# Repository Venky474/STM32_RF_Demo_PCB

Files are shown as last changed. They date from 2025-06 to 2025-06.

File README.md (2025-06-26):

# STM32_RF_Demo_PCB

This is a custom STM32 RF PCB designed using KiCad.

## Contents
- 🧩 KiCad Project Files (`.kicad_pro`, `.kicad_pcb`, `.kicad_sch`)
- 📦 Gerber Files (in `.rar`)
- 📄 BOM: `BOM_Output.csv`
- 🤖 Pick and Place: `STM32_RF.cpl`

## Preview

Preview of the STM32_RF PCB layout (generated using KiCad 3D viewer).
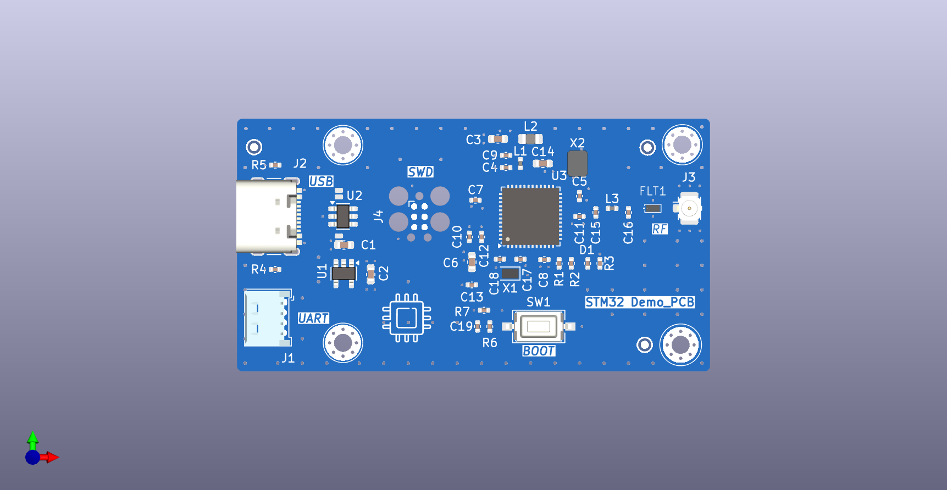
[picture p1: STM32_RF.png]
3D PCB View


## License
[MIT](LICENSE) or specify your own

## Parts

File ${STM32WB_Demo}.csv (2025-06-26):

Reference | Value | Footprint | Datasheet | Qty | DNP | Exclude from BOM | Exclude from Board
C1,C2,C3,C6,C14 | 4.7uF | Capacitor_SMD:C_0603_1608Metric | ~ | 5
C4,C5,C7,C8,C9,C10,C11,C12,C13,C19 | 100nF | Capacitor_SMD:C_0402_1005Metric | ~ | 10
C15 | 0.8pF | Capacitor_SMD:C_0402_1005Metric | ~ | 1
C16 | 0.3pF | Capacitor_SMD:C_0402_1005Metric | ~ | 1
C17,C18 | 10p | Capacitor_SMD:C_0402_1005Metric | ~ | 2
D1 | LED | Capacitor_SMD:C_0402_1005Metric | ~ | 1
FID1,FID2,FID3 | Fiducial | Fiducial:Fiducial_1mm_Mask2mm | ~ | 3 |  | Excluded from BOM
FLT1 | DLF162500LT-5028A1 | STM32_RF:Untitled | https://product.tdk.com/en/system/files | 1
H1,H2,H3,H4 | MountingHole_Pad | MountingHole:MountingHole_2.2mm_M2_Pad_Via | ~ | 4 |  | Excluded from BOM
J1 | Conn_01x04 | Connector_Molex:Molex_PicoBlade_53048-0410_1x04_P1.25mm_Horizontal | ~ | 1
J2 | USB_C_Receptacle_USB2.0_16P | Connector_USB:USB_C_Receptacle_GCT_USB4105-xx-A_16P_TopMnt_Horizontal | https://www.usb.org/sites/default/files/documents/usb_type-c.zip | 1
J3 | Conn_Coaxial | Connector_Coaxial:U.FL_Hirose_U.FL-R-SMT-1_Vertical | ~ | 1
J4 | TC2030 | Connector:Tag-Connect_TC2030-IDC-FP_2x03_P1.27mm_Vertical | https://www.tag-connect.com/wp-content/uploads/bsk-pdf-manager/TC2030-CTX_1.pdf | 1 |  | Excluded from BOM
L1 | 10nH | Inductor_SMD:L_0402_1005Metric | ~ | 1
L2 | 10uH | Inductor_SMD:L_0805_2012Metric | ~ | 1
L3 | 2.7nH | Inductor_SMD:L_0402_1005Metric | ~ | 1
R1,R2,R6 | 100R | Capacitor_SMD:C_0402_1005Metric | ~ | 3
R3 | 220R | Capacitor_SMD:C_0402_1005Metric | ~ | 1
R4,R5 | 5K1 | Capacitor_SMD:C_0402_1005Metric | ~ | 2
R7 | 5k1 | Capacitor_SMD:C_0402_1005Metric | ~ | 1
SW1 | SW_Push | Button_Switch_SMD:SW_Tactile_SPST_NO_Straight_CK_PTS636Sx25SMTRLFS | ~ | 1
U1 | MIC5365-3.3YD5 | Package_TO_SOT_SMD:SOT-23-5 | http://ww1.microchip.com/downloads/en/DeviceDoc/mic5365.pdf | 1
U2 | USBLC6-2SC6 | Package_TO_SOT_SMD:SOT-23-6 | https://www.st.com/resource/en/datasheet/usblc6-2.pdf | 1
U3 | STM32WB55CEU6 | Package_DFN_QFN:QFN-48-1EP_7x7mm_P0.5mm_EP5.6x5.6mm | https://www.st.com/resource/en/datasheet/stm32wb55ce.pdf | 1
X1 | 32KHz768 | Crystal:Crystal_SMD_2012-2Pin_2.0x1.2mm | ~ | 1
X2 | 32MHz | Crystal:Crystal_SMD_2016-4Pin_2.0x1.6mm | ~ | 1

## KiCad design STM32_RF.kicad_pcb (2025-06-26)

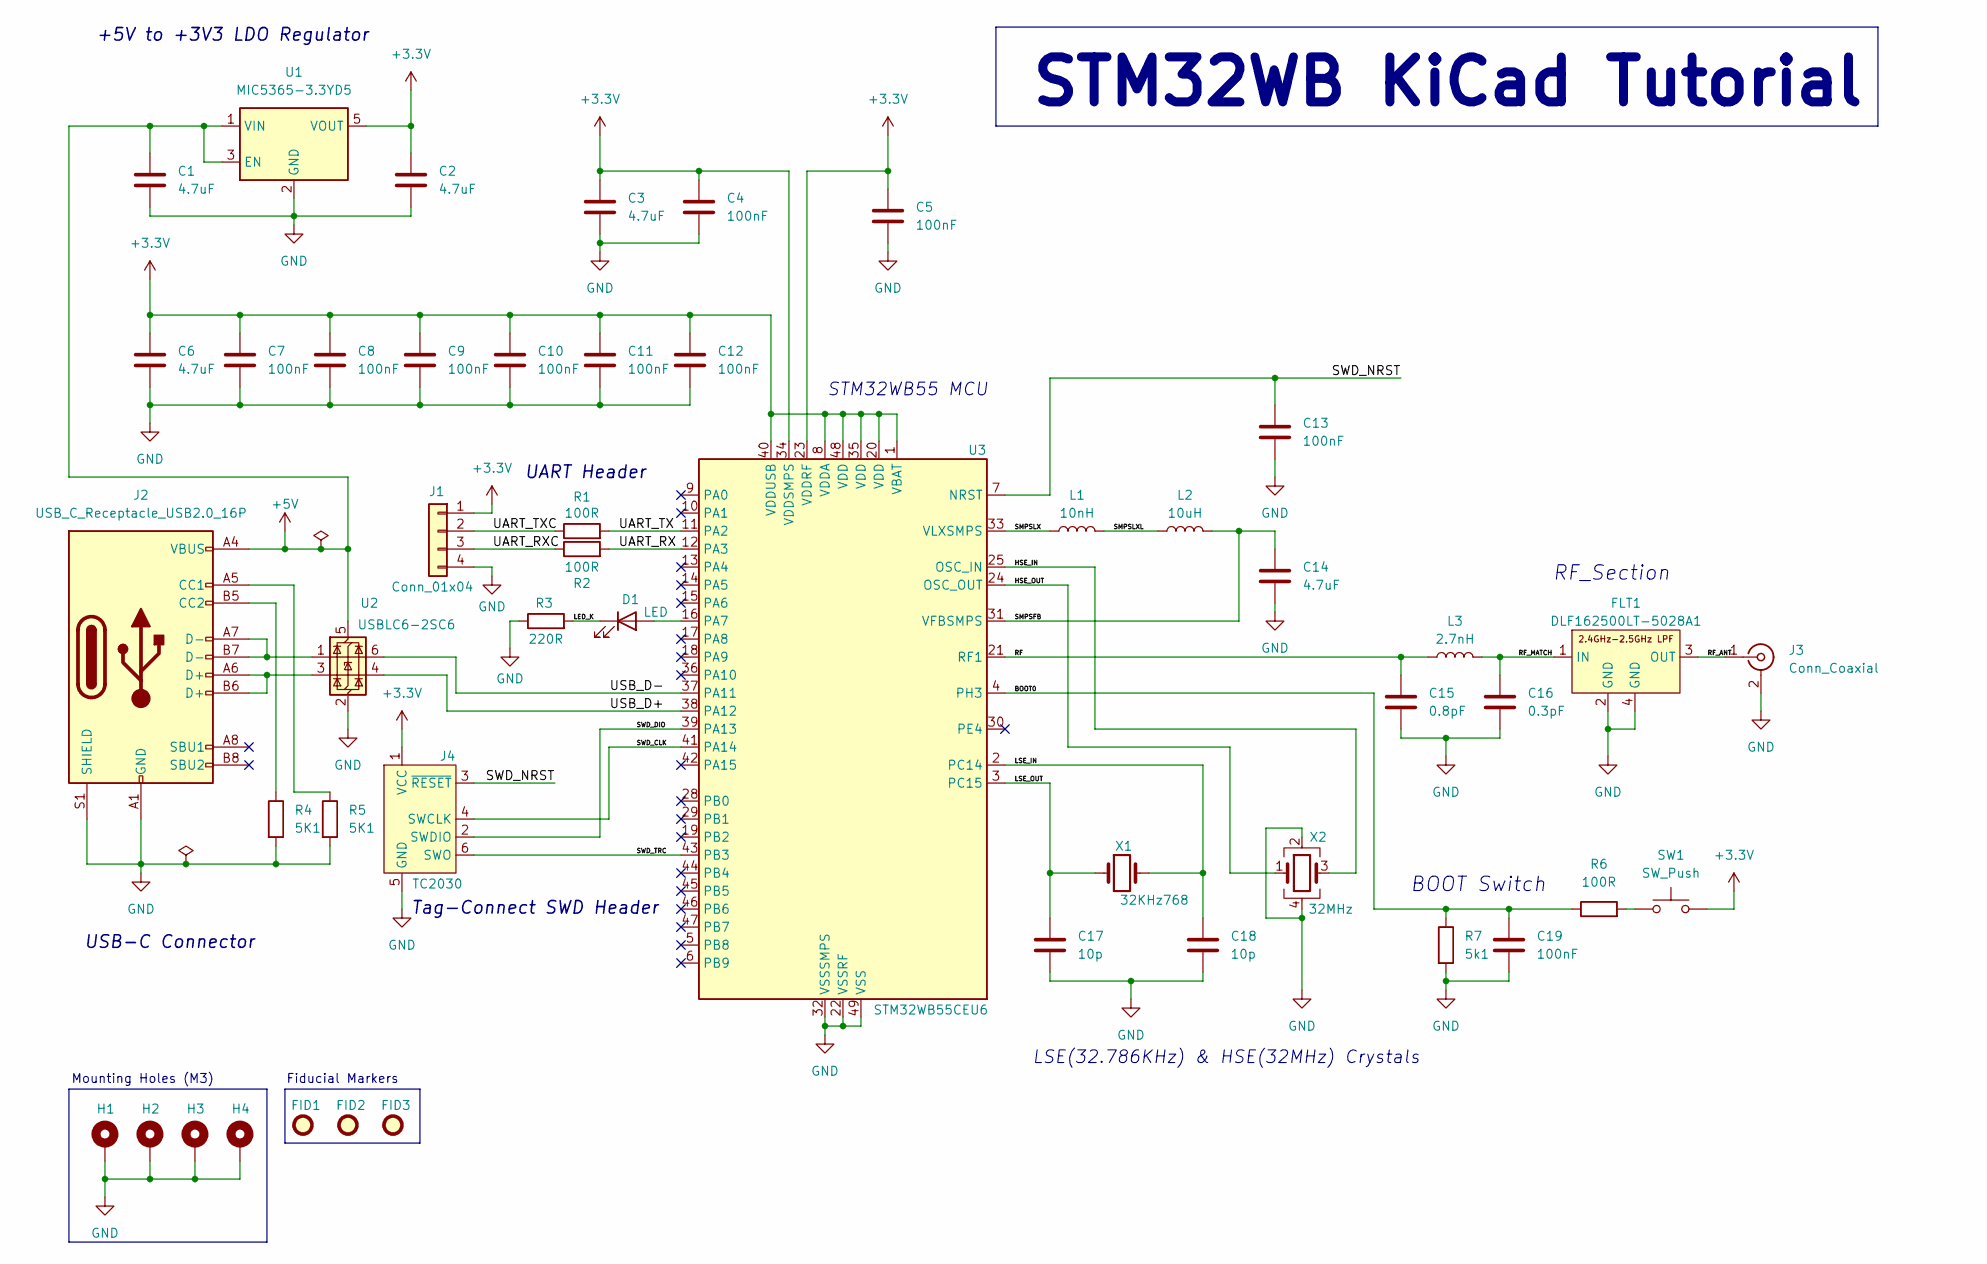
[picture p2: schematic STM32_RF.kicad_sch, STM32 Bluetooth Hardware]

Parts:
C1, C2, C3, C6, C14: 4.7uF; C_0603_1608Metric
C4, C5, C7, C8, C9, C10, C11, C12, C13, C19: 100nF; C_0402_1005Metric
C15: 0.8pF; C_0402_1005Metric
C16: 0.3pF; C_0402_1005Metric
C17, C18: 10p; C_0402_1005Metric
D1: LED; C_0402_1005Metric
FID1, FID2, FID3: Fiducial; Fiducial_1mm_Mask2mm
FLT1: DLF162500LT-5028A1; Untitled
H1: MountingHole_Pad; MountingHole_3.2mm_M3_Pad
H2, H3, H4: MountingHole_Pad; MountingHole_2.2mm_M2_Pad_Via
J1: Conn_01x04; Molex_PicoBlade_53048-0410_1x04_P1.25mm_Horizontal
J2: USB_C_Receptacle_USB2.0_16P; USB_C_Receptacle_GCT_USB4105-xx-A_16P_TopMnt_Horizontal
J3: Conn_Coaxial; U.FL_Hirose_U.FL-R-SMT-1_Vertical
J4: TC2030; Tag-Connect_TC2030-IDC-FP_2x03_P1.27mm_Vertical
L1: 10nH; L_0402_1005Metric
L2: 10uH; L_0805_2012Metric
L3: 2.7nH; L_0402_1005Metric
R1, R2, R6: 100R; C_0402_1005Metric
R3: 220R; C_0402_1005Metric
R4, R5: 5K1; C_0402_1005Metric
R7: 5k1; C_0402_1005Metric
SW1: SW_Push; SW_Tactile_SPST_NO_Straight_CK_PTS636Sx25SMTRLFS
U1: MIC5365-3.3YD5; SOT-23-5
U2: USBLC6-2SC6; SOT-23-6
U3: STM32WB55CEU6; QFN-48-1EP_7x7mm_P0.5mm_EP5.6x5.6mm
X1: 32KHz768; Crystal_SMD_2012-2Pin_2.0x1.2mm
X2: 32MHz; Crystal_SMD_2016-4Pin_2.0x1.6mm

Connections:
+3.3V: C2.1, C3.1, C4.1, C5.1, C6.1, C7.1, C8.1, C9.1, C10.1, C11.1, C12.1, J1.1, J4.1 (VCC), SW1.2, U1.5 (VOUT), U3.1 (VBAT), U3.8 (VDDA), U3.20 (VDD), U3.23 (VDDRF), U3.34 (VDDSMPS), U3.35 (VDD), U3.40 (VDDUSB), U3.48 (VDD)
+5V: C1.1, J2.A4 (VBUS), J2.A9 (VBUS), J2.B4 (VBUS), J2.B9 (VBUS), U1.1 (VIN), U1.3 (EN), U2.5 (VBUS)
/BOOT0: C19.1, R6.1, R7.1, U3.4 (PH3)
/HSE_IN: U3.25 (OSC_IN), X2.3
/HSE_OUT: U3.24 (OSC_OUT), X2.1
/LED_K: D1.1 (K), R3.2
/LSE_IN: C18.1, U3.2 (PC14), X1.2
/LSE_OUT: C17.1, U3.3 (PC15), X1.1
/RF: C15.1, L3.1, U3.21 (RF1)
/RF_ANT: FLT1.3 (OUT), J3.1 (In)
/RF_MATCH: C16.1, FLT1.1 (IN), L3.2
/SMPSFB: C14.1, L2.2, U3.31 (VFBSMPS)
/SMPSLX: L1.1, U3.33 (VLXSMPS)
/SMPSLXL: L1.2, L2.1
/SWD_CLK: J4.4 (SWCLK), U3.41 (PA14)
/SWD_DIO: J4.2 (SWDIO), U3.39 (PA13)
/SWD_NRST: C13.1, J4.3 (~RESET), U3.7 (NRST)
/SWD_TRC: J4.6 (SWO), U3.43 (PB3)
/UART_RX: R2.2, U3.12 (PA3)
/UART_RXC: J1.3, R2.1
/UART_TX: R1.2, U3.11 (PA2)
/UART_TXC: J1.2, R1.1
/USB_D+: U2.4 (I/O2), U3.38 (PA12)
/USB_D-: U2.6 (I/O1), U3.37 (PA11)
GND: C1.2, C2.2, C3.2, C4.2, C5.2, C6.2, C7.2, C8.2, C9.2, C10.2, C11.2, C12.2, C13.2, C14.2, C15.2, C16.2, C17.2, C18.2, C19.2, FLT1.2 (GND), FLT1.4 (GND), H1.1, H2.1, H3.1, H4.1, J1.4, J2.A1 (GND), J2.A12 (GND), J2.B1 (GND), J2.B12 (GND), J2.S1 (SHIELD), J3.2 (Ext), J4.5 (GND), R3.1, R4.2, R5.2, R7.2, U1.2 (GND), U2.2 (GND), U3.22 (VSSRF), U3.32 (VSSSMPS), U3.49 (VSS), X2.2, X2.4
unnamed: D1.2 (A), U3.16 (PA7)
unnamed: J2.A5 (CC1), R5.1
unnamed: J2.B5 (CC2), R4.1
unnamed: J2.A6 (D+), J2.B6 (D+), U2.3 (I/O2)
unnamed: J2.A7 (D-), J2.B7 (D-), U2.1 (I/O1)
unnamed: R6.2, SW1.1

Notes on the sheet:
STM32WB KiCad Tutorial
STM32WB55 MCU
Fiducial Markers
Tag-Connect SWD Header
UART Header
Mounting Holes (M3)
RF_Section
+5V to +3V3 LDO Regulator
USB-C Connector
BOOT Switch
LSE(32.786KHz) & HSE(32MHz) Crystals

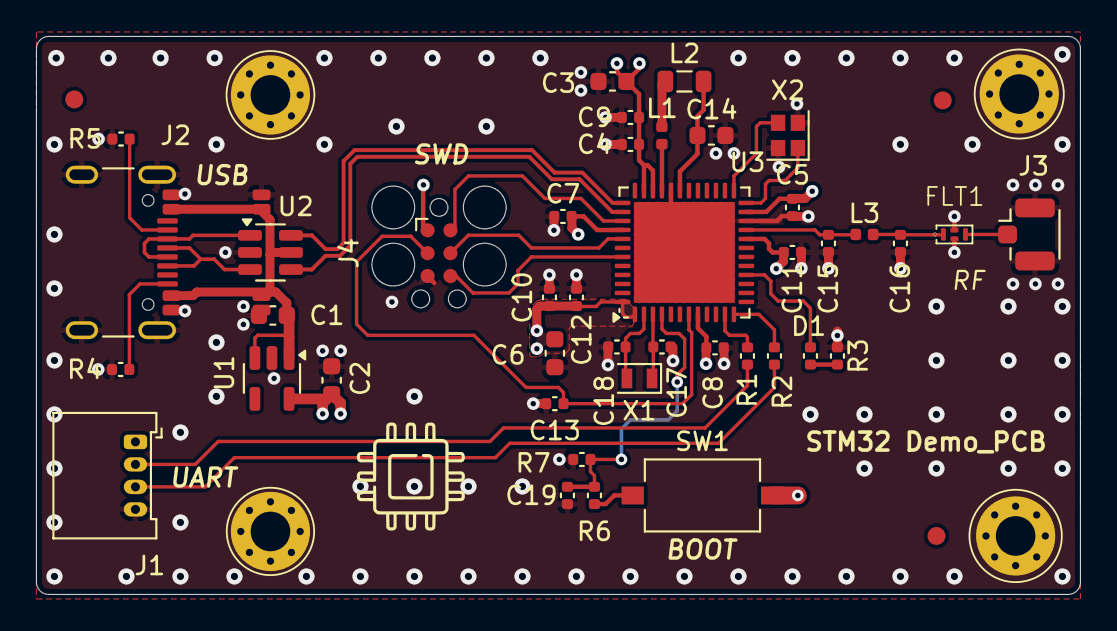
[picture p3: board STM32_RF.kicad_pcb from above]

Board: 4 copper layers, 58.0 x 31.0 mm, 49 parts (0 on the bottom side), 31 nets.

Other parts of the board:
G: LOGO
